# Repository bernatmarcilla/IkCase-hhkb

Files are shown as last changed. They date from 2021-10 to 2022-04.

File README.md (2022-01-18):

# IkCase-hhkb

_An original HHKB layout Acrylic Case_

_Stacked Acrylic Case for original Happy Hacking Keyboard layout, compatible with standard 60% PCBs_

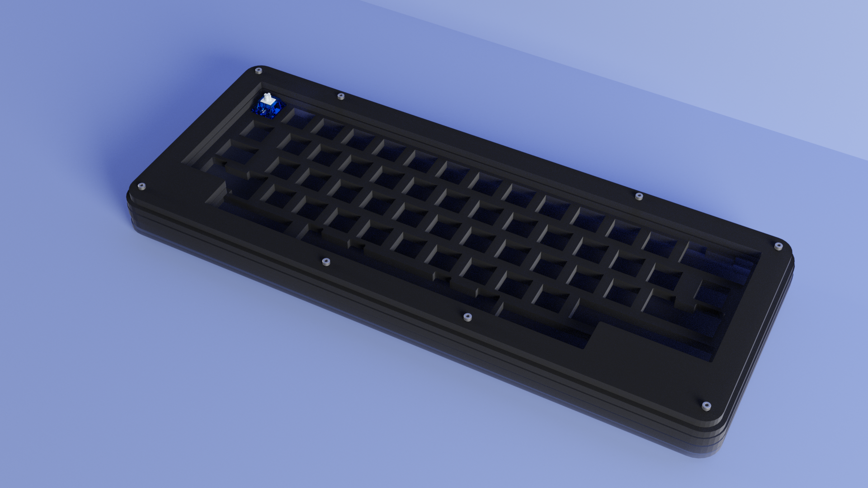
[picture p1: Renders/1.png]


The goal of this project is to offer a stacked acrylic alternative to the original HHKB case. This alternative has some measurements modifications to get the best fit between the PCB and the case.

## Layout:

- **Top row**: The right corner can be a 2 1U keys (like the renders) or a 1 2U stab key.  

- **Bottom row - Fixed Layout**: 1U left Super, 1.5U left Alt, 6.25U space bar, 1.5U right Alt, 1U right Super. 

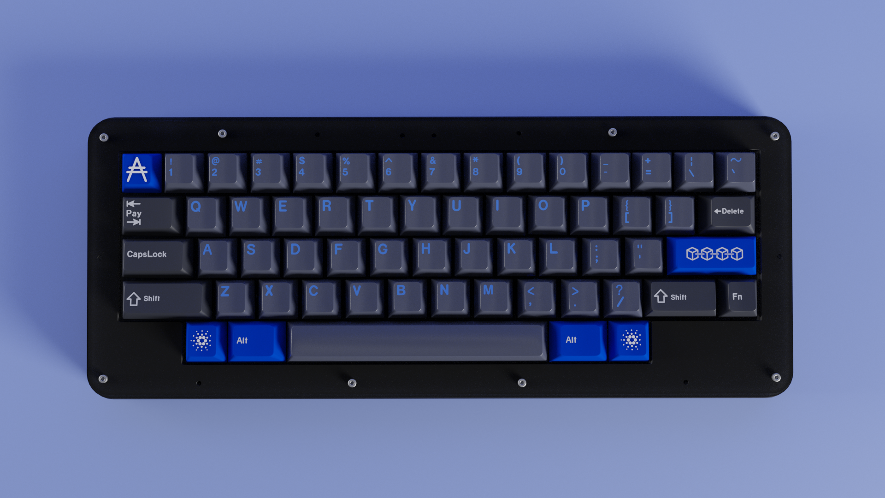
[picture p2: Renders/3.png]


---

## Acrilic Layers

The case is made with 5 layers of acrylic that are stacked on top of each other and held together with 8 **M3** screws (screw holes are 3mm diameter). 
Note that this case has been developed for a PCB that has the **USB underneath of the PCB**. This case **won't fit with a PCB that has the USB on top**. 

- **L6**: The top piece of the case. The ideal thickness is 4mm (4 millimetres). 

- **L5**: This piece is much similar to the top piece and the ideal thickness is also 4mm (4 millimetres). 

- **L4-plate-hhkb**: This is the switchplate of the keyboard. Will hold the switches and the ideal thickness is 5mm (5 millimetres). 

- **L1_L2_L3**: This piece is placed between the plate and the base piece to offer space to the PCB and the ideal thickness is 5mm (5 millimetres). 

- **L0**: The bottom piece that closes the case. The ideal thickness is 3mm (3 millimetres). Like **L1_L2_L3** piece, has the USB port exit. 

---
## Final Prototype

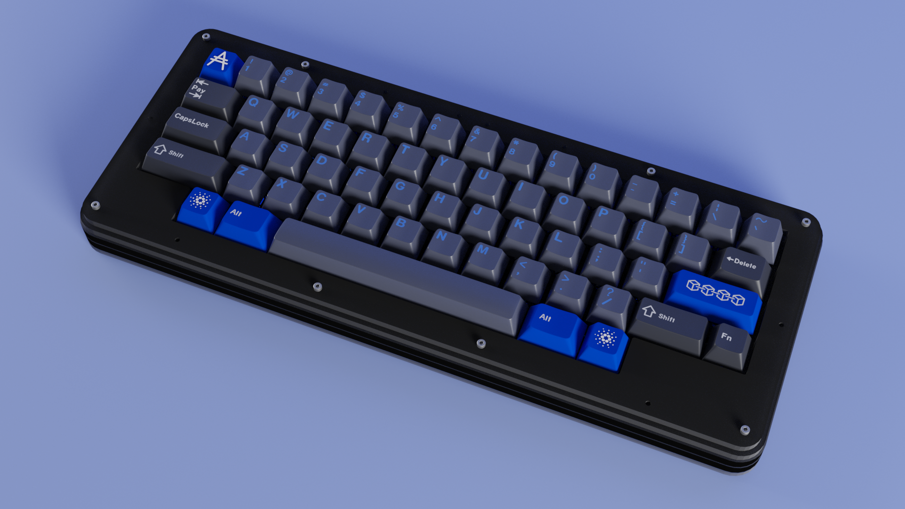
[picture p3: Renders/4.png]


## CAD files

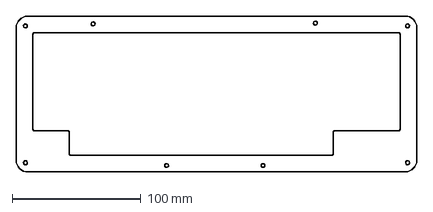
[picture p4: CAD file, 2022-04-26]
DXF-Files/L6.dxf
311.7 x 121.3 mm

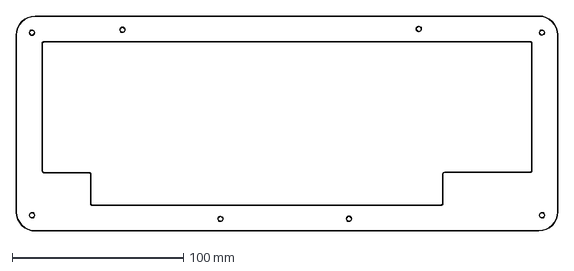
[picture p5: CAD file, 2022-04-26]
DXF-Files/L5.dxf
315.7 x 125.3 mm

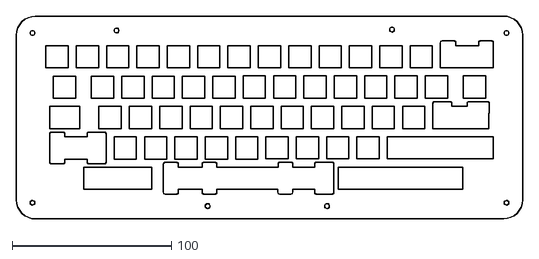
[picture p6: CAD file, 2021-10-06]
DXF-Files/L4-plate-hhkb.dxf
317.7 x 127.3

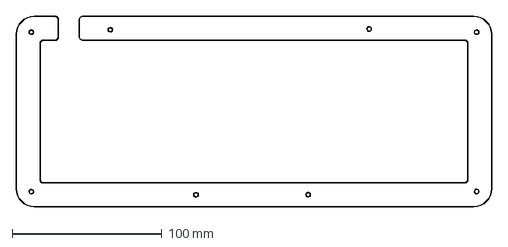
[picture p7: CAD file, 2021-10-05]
DXF-Files/L1_L2_L3.dxf
317.7 x 127.3 mm

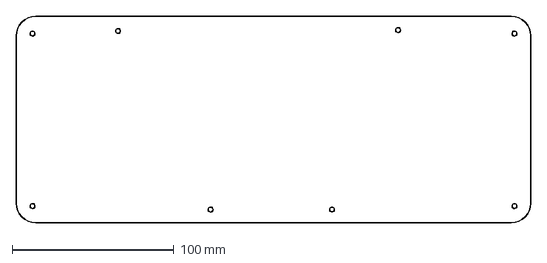
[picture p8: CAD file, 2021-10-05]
DXF-Files/L0.dxf
317.7 x 127.2 mm

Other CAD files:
DWG-Files/L0.dwg
DWG-Files/L1_L2_L3.dwg
DWG-Files/L4-plate-hhkb.dwg
DWG-Files/L5.dwg
DWG-Files/L6.dwg

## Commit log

2021-10-05 DXF files
    [L0.dxf, L1_L2_L3.dxf, L4-plate-hhkb.dxf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]
2021-10-05 3M holes
    [L0.dxf, L1_L2_L3.dxf, L4-plate-hhkb.dxf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]
2021-10-06 Plate stabs fix
    [#L4-plate-hhkb.dxf]
2021-10-06 Redundant files
    [#L4-plate-hhkb.dxf, L4-plate-hhkb.dxf]
2021-10-06 plate Space stab
    [L4-plate-hhkb.dxf]
2021-10-06 DWG files
    [L0.dwg, L1_L2_L3.dwg, L4-plate-hhkb.dwg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]
2021-10-08 Case render
2022-01-18 layers thickness & M3 screws info; close #1
2022-04-26 updated dwg files
    [L5.dwg, L6.dwg]
